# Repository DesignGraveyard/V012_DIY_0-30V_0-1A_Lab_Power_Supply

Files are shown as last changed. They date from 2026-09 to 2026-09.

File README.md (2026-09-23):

# Description

Build a cheap and reliable 0–30V, 0–1A bench power supply using standard components like the LM317 and NE555. 
This design is based on a ON-Semiconductors application note but simplified with common “jellybean” parts and a NE555 charge pump to generate the negative voltage reference to achieve output control down to 0 Volt & 0 Ampere.

The video below shows the power supply in action, assembly tips, how to manage the thermals, a LM317 offline HTML tool including losses and an explanation how it works!

# Check out the video:

Watch the video (https://youtu.be/TmOTqNCIk3g)

# Schematic of the power supply

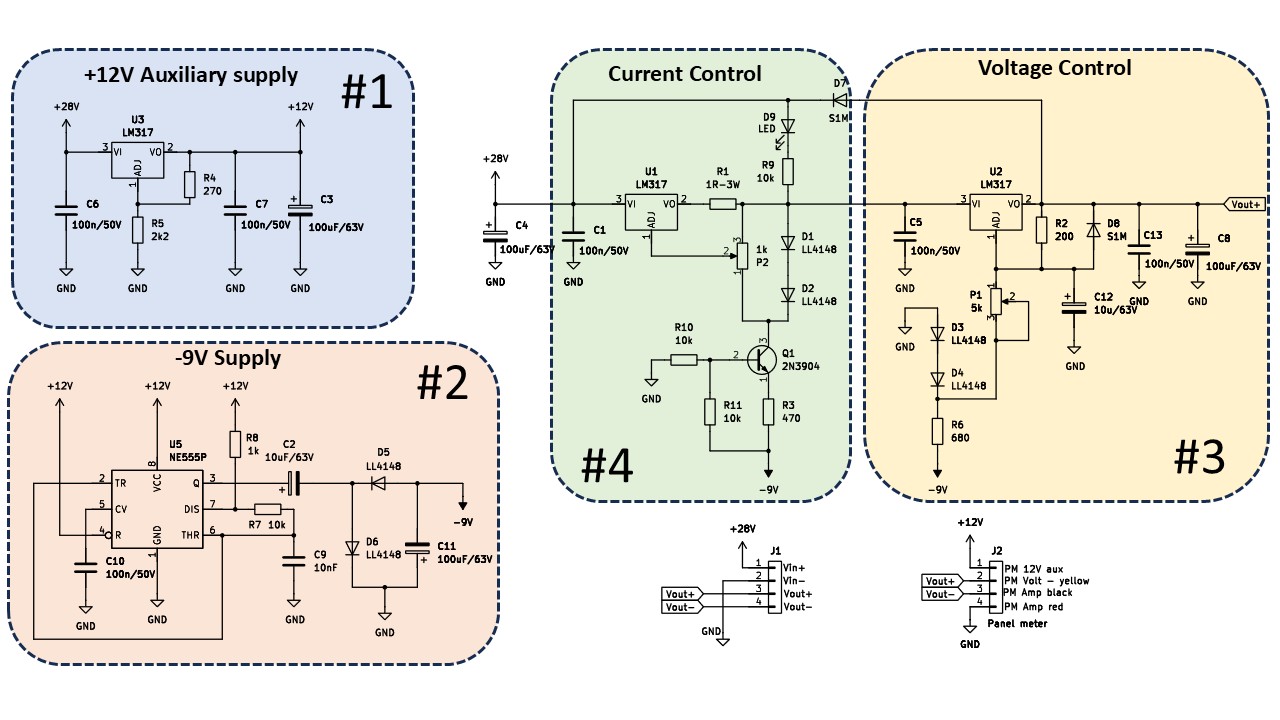
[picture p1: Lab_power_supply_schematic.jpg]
Lab Power Supply


# PCB Connections of the power supply PCBA:  

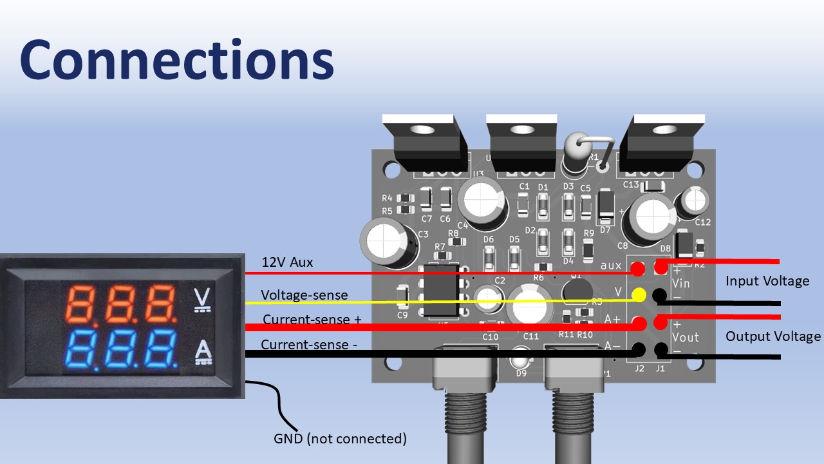
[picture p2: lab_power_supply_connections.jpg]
Lab Power Supply


#  Offline LM317 calculator tool, including losses: 

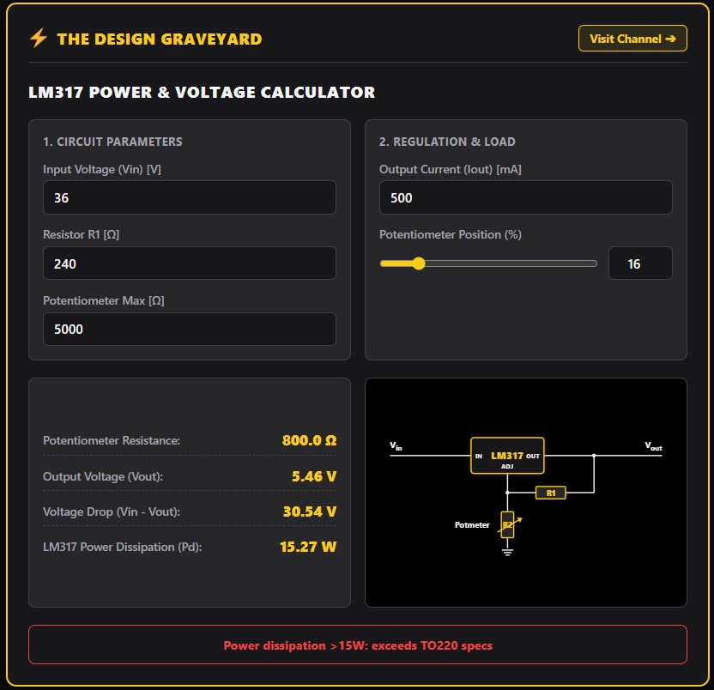
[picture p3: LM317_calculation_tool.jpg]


# Files:  
  
-PCB Gerber files to order the PCBs: (PCB_GERBER_V011_LM317_Lab_power_supply_0-30V.zip).  
-KiCAD 10 Files: PCB source files to adapt the design.  
-LTSpice simulation: Simulation file of the full power supply, all spice models included.  
-LM317_calculator_TDG: An offline LM317 calculator tool including losses in the LM317.

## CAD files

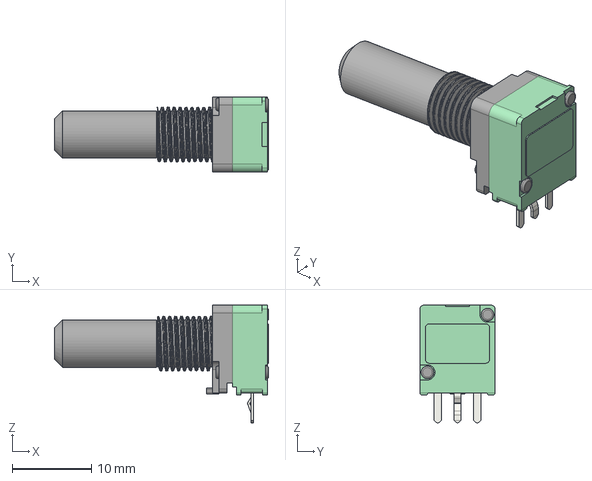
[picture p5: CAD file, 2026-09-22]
KiCAD10_Files/potentiometers/ALPS-RK097.step
27.1 x 9.50 x 14.9 mm

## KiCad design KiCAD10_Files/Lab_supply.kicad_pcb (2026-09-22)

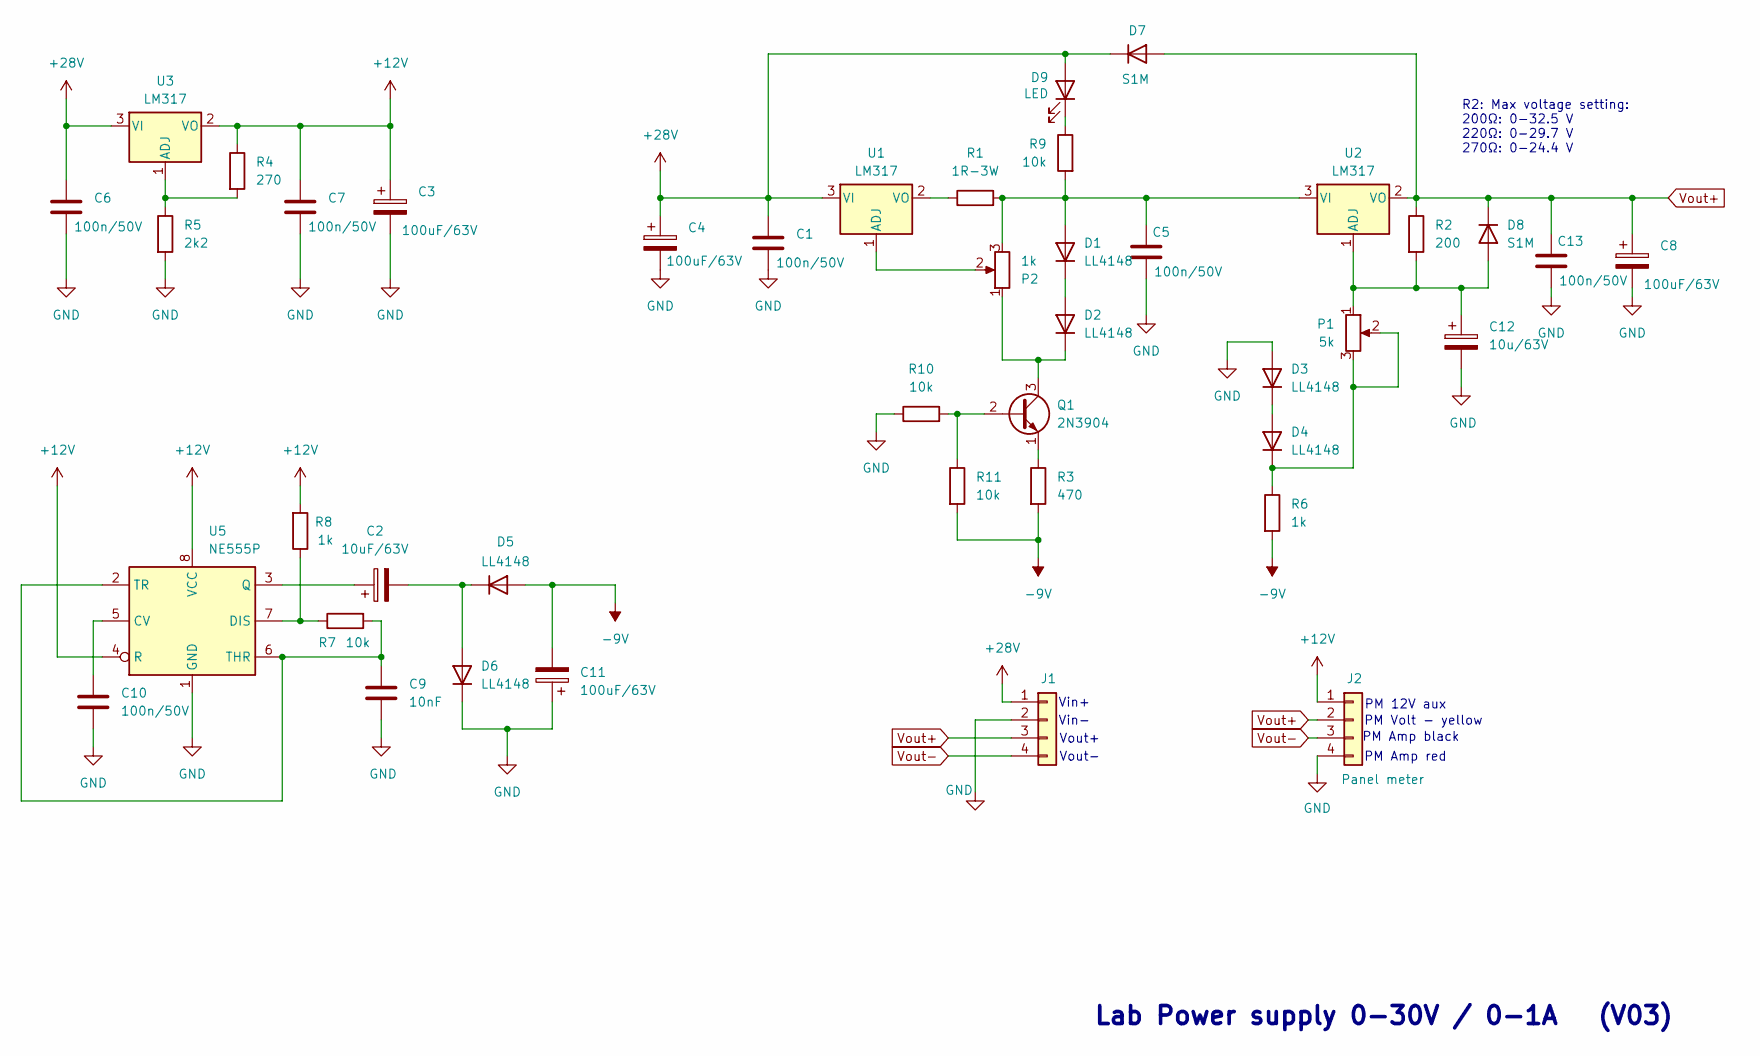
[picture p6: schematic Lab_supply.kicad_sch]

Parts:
C1, C5, C6, C7, C10, C13: 100n/50V; C_1206_3216Metric_Pad1.33x1.80mm_HandSolder
C2: 10uF/63V; CP_Radial_D5.0mm_P2.50mm
C3, C4, C8, C11: 100uF/63V; CP_Radial_D8.0mm_P3.50mm
C9: 10nF; C_1206_3216Metric_Pad1.33x1.80mm_HandSolder
C12: 10u/63V; CP_Radial_D5.0mm_P2.50mm
D1, D2, D3, D4, D5, D6: LL4148; D_MiniMELF
D7, D8: S1M; D_SMA
D9: LED; LED_D3.0mm_Clear
J1: in-out; SolderWire-0.5sqmm_1x04_P4.8mm_D0.9mm_OD2.3mm
J2: Panel meter; SolderWire-0.5sqmm_1x04_P4.8mm_D0.9mm_OD2.3mm
P1: 5k; Potentiometer_Alps_RK097_Single_Horizontal
P2: 1k; Potentiometer_Alps_RK097_Single_Horizontal
Q1: 2N3904; TO-92_Inline
R1: 1R-3W; R_Axial_DIN0414_L11.9mm_D4.5mm_P5.08mm_Vertical
R2: 200; R_0805_2012Metric_Pad1.20x1.40mm_HandSolder
R3: 470; R_0805_2012Metric_Pad1.20x1.40mm_HandSolder
R4: 270; R_0805_2012Metric_Pad1.20x1.40mm_HandSolder
R5: 2k2; R_0805_2012Metric_Pad1.20x1.40mm_HandSolder
R6, R8: 1k; R_0805_2012Metric_Pad1.20x1.40mm_HandSolder
R7, R10, R11: 10k; R_0805_2012Metric_Pad1.20x1.40mm_HandSolder
R9: 10k; R_1206_3216Metric_Pad1.30x1.75mm_HandSolder
U1, U2, U3: LM317; TO-220-3_Vertical
U5: NE555P; DIP-8_W7.62mm

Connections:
+12V: C3.1, C7.1, J2.1, R4.1, R8.2, U3.2 (VO), U5.4 (R), U5.8 (VCC)
+28V: C1.1, C4.1, C6.1, D7.1 (K), D9.2 (A), J1.1, U1.3 (VI), U3.3 (VI)
-9V: C11.2, D5.2 (A), R3.2, R6.2, R11.2
GND: C1.2, C3.2, C4.2, C5.2, C6.2, C7.2, C8.2, C9.2, C10.2, C11.1, C12.2, C13.2, D3.2 (A), D6.1 (K), J1.2, J2.4, R5.2, R10.1, U5.1 (GND)
unnamed: C5.1, D1.2 (A), P2.3, R1.2, R9.2, U2.3 (VI)
unnamed: D1.1 (K), D2.2 (A)
unnamed: D2.1 (K), P2.1, Q1.3 (C)
unnamed: D3.1 (K), D4.2 (A)
unnamed: D4.1 (K), P1.2, P1.3, R6.1
unnamed: C2.2, D5.1 (K), D6.2 (A)
unnamed: C12.1, D8.2 (A), P1.1, R2.2, U2.1 (ADJ)
unnamed: D9.1 (K), R9.1
unnamed: Q1.2 (B), R10.2, R11.1
unnamed: Q1.1 (E), R3.1
unnamed: P2.2, U1.1 (ADJ)
unnamed: R1.1, U1.2 (VO)
unnamed: R4.2, R5.1, U3.1 (ADJ)
unnamed: C10.1, U5.5 (CV)
unnamed: R7.1, R8.1, U5.7 (DIS)
unnamed: C2.1, U5.3 (Q)
unnamed: C9.1, R7.2, U5.2 (TR), U5.6 (THR)
Vout+: C8.1, C13.1, D7.2 (A), D8.1 (K), J1.3, J2.2, R2.1, U2.2 (VO)
Vout-: J1.4, J2.3

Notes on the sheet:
PM 12V aux
Vin+
PM Volt - yellow
Lab Power supply 0-30V / 0-1A (V03)
Vout+
Vin-
PM Amp black
Vout-
R2: Max voltage setting: 200Ω: 0-32.5 V 220Ω: 0-29.7 V 270Ω: 0-24.4 V
PM Amp red

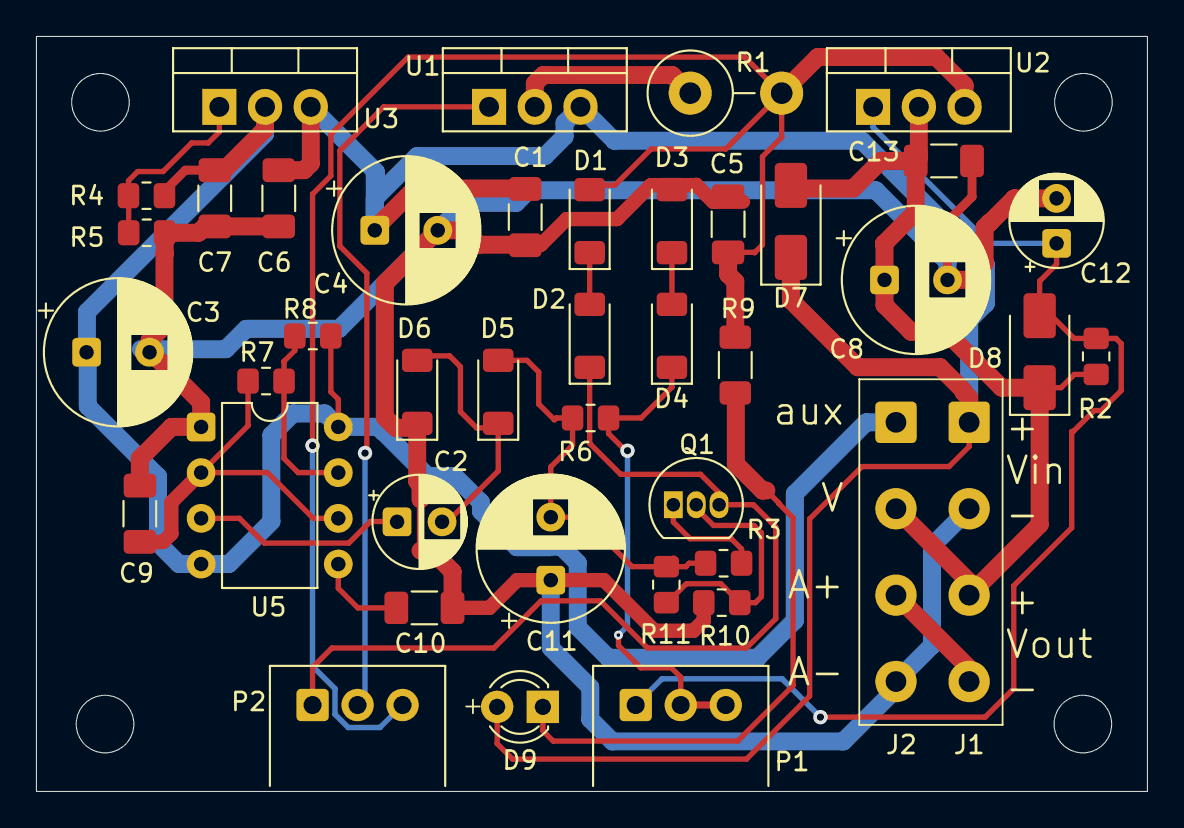
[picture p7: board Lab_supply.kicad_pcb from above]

Board: 2 copper layers, 61.7 x 41.9 mm, 42 parts (0 on the bottom side), 23 nets.

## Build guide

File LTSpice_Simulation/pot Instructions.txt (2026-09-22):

-- Download the pot.zip  at https://github.com/brandondrury/LTspice-Libraries/tree/main

-- Find your C:\Users\YOUR_USERNAME\Documents\LTspiceXVII\lib\  folder
-- Place pot.asy in your  "sym" folder.    C:\Users\YOUR_USERNAME\Documents\LTspiceXVII\lib\sym\
-- Place pot.sub in your "sub" folder.  C:\Users\YOUR_USERNAME\Documents\LTspiceXVII\lib\ sub\
-- Click the text tool.  Select "SPICE Directive" and paste in .include pot.sub.
-- Restart LTspice
-- Creat a new schematic.  Press F2.  You should see "Pot".

The wiper is on a 0-1 scale.  1 = 100%.  0.5 = 50%.
There is a glitch that occurs if a resistor is 0 ohms in LtSpice.  So, this pot actually is limited from 0.001 - 0.999 so don't freak out if your values are off by 0.1% on extreme settings.
